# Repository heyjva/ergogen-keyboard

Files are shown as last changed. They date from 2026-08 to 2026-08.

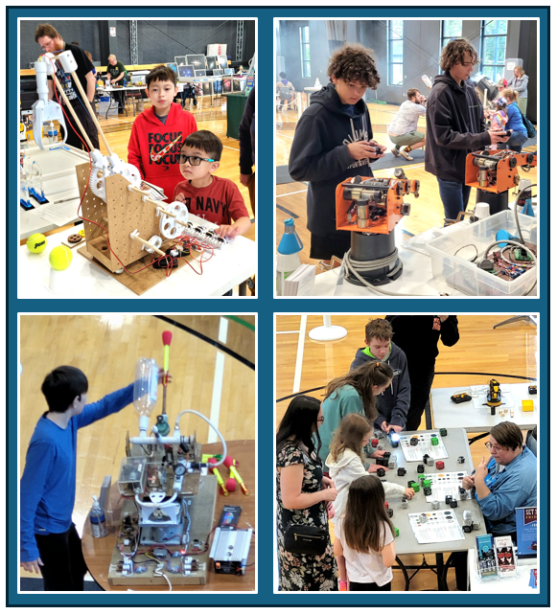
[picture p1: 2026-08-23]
footprints/4_Photos_Kitsap_Stem_Expo_2025.png

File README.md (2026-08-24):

# ergogen-keyboard

Ergogen keyboard project, migrated to **KiCad 8** with a local preview/edit app.

This repo contains the full keyboard definition: a **split ergo board** with a
matrix, thumb cluster, rotary encoder and its own nice!nano controller **per
half**. It is a **wireless split** (independent MCU on each half, e.g. ZMK).
The numpad that used to live in the old `heyjva/ergogen` fork is **not** part of
this repo.

## Split layout: left + right

One `config.yaml` generates **both halves** as separate PCBs via ergogen's
`mirror`:

- The `points.zones.main` / `thumb` zones carry a `mirror:` block, so ergogen
  emits `mirror_*` points for the right half.
- `pcbs.main_left` selects source points (`where: -/mirror_/`); `pcbs.main_right`
  selects mirror points (`where: /mirror_/`) and anchors positioned footprints
  to `mirror_main_*` refs.
- The right half's **side-actuated power/reset switches** get `+180°` rotation
  so their actuators face the mirrored board edge.
- Both halves share the same net names (P11..P21, P2, etc.). That is safe
  because they are **separate PCBs / separate MCUs** — the nets never physically
  connect across boards.

Ergogen writes `output/pcbs/main_left.kicad_pcb` and
`output/pcbs/main_right.kicad_pcb`. The KiCad projects live in:

| Path | Description |
|---|---|
| `kicad/left/`  | Left half KiCad project. **Fully routed** + DRC-clean (JLCPCB rules). |
| `kicad/right/` | Right half KiCad project (mirror image). Generated, **not yet routed**. |
| `kicad/3d_models/` | Shared STEP/WRL 3D models (symlinked into each half). |

Build/regenerate a half's KiCad project from ergogen output:

```bash
node <ergogen> . -o output           # regenerate both PCBs
./kicad/build_kicad_project.sh right  # (re)build the right-half project
# ./kicad/build_kicad_project.sh left   # WARNING: wipes the routed left PCB
```

## Contents

| Path | Description |
|---|---|
| `config.yaml` | Ergogen definition (KiCad 8, Back-side hotswap, mirrored split). |
| `key.json` | Original KLE source, kept for reference. |
| `footprints/ceoloide/` | Vendored KiCad 8 footprints used by the board. |
| `output/` | Generated output (DXF outlines + `main_left`/`main_right` PCBs). |

## Footprints (KiCad 8)

The board uses these footprints from
[`ceoloide/ergogen-footprints`](https://github.com/ceoloide/ergogen-footprints),
vendored under `footprints/ceoloide/`:

- `switch_choc_v1_v2` — Kailh Choc hotswap switches
- `diode_tht_sod123` — per-key diodes
- `mcu_nice_nano` — nice!nano controller
- `encoder_evqwgd001` — Panasonic EVQWGD001 rotary encoder
- `battery_connector_jst_ph_2`, `power_switch_smd_side`,
  `reset_switch_smd_side`, `mounting_hole_plated`

Keys/diodes/MCU/encoder are on the **Back (`B`)** side; the side-actuated
power/reset switches are on the **Front (`F`)**. Each half is non-reversible on
its own; the *split* mirror is what produces the right half.

## Wiring notes (important for firmware)

The matrix uses 7 columns and 4 rows:

- Columns: `P21 P20 P19 P18 P17 P16 P15`
- Rows: `P14 P13 P12 P11`

The nice!nano does **not** break out physical pins named `P11`, `P12`, `P13`,
or `P17`. In `config.yaml` those logical nets are therefore routed onto spare
physical nice!nano pins, and the nice!view SPI signals are assigned as follows:

| Logical net | Physical nice!nano pin |
|---|---|
| `P17` (index column) | `P4` |
| `P13` (home row) | `P5` |
| `P12` (top row) | `P6` |
| `P11` (num row) | `P7` |
| `MOSI` (display) | `P8` |
| `SCK` (display) | `P9` |
| `CS` (display) | `P3` |

The remaining matrix nets (`P21 P20 P19 P18 P16 P15 P14`) map 1:1 to the
same-named physical pins. **Update your firmware pin map to match the physical
pins above.** (In the original fork these four nets were never connected to the
MCU — this project fixes that.)

## 3D models

The footprints are wired to reference 3D models but the model asset files are
not included here. To see 3D renders in KiCad, drop the appropriate `.step` /
`.wrl` files into `models/` and point the footprints' `*_3dmodel_filename`
params at them. 3D models do **not** render in the browser preview — only in
KiCad.

## Previewing & editing locally

The preview/edit app is a patched fork of
[`ceoloide/ergogen-gui`](https://github.com/ceoloide/ergogen-gui) at
[`heyjva/ergogen-gui`](https://github.com/heyjva/ergogen-gui). It runs a local
web server and, unlike the stock GUI, includes a **"Save to File"** button that
writes changes straight back to this repo's `config.yaml` — and it works in
**Firefox / Zen**.

### One-time setup

```bash
# clone both repos as siblings
git clone https://github.com/heyjva/ergogen-keyboard.git
git clone https://github.com/heyjva/ergogen-gui.git

cd ergogen-gui
npm install -g pnpm   # if you don't have pnpm
PNPM_CONFIG_BLOCK_EXOTIC_SUBDEPS=false \
  ERGOGEN_VERSION=github:ceoloide/ergogen#v4.3.0 \
  pnpm install --no-frozen-lockfile
```

### Run it

```bash
cd ergogen-gui
./start.sh
```

This launches:

1. a tiny **save-helper** on `http://localhost:3001` (writes `config.yaml`), and
2. the **GUI** on `http://localhost:3000`.

Open <http://localhost:3000> in **Firefox / Zen**. The editor auto-loads this
repo's `config.yaml`. Edit it, then click **Save to File** (or press
**Ctrl/Cmd+S**) to write your changes back to `config.yaml` on disk. Commit with
git as usual.

> The save-helper is required because Firefox cannot write local files directly
> from a web page. It binds to `127.0.0.1` only and only ever writes this repo's
> `config.yaml`.

If you keep the repos somewhere other than as siblings, point the helper at the
file explicitly:

```bash
CONFIG_PATH=/absolute/path/to/ergogen-keyboard/config.yaml ./start.sh
```

## Regenerating outputs from the command line

The GUI is for previewing/editing. To regenerate the DXF/KiCad files on disk
from `config.yaml`, run Ergogen v4.3.0 against this folder:

```bash
# from a checkout of ceoloide/ergogen at branch v4.3.0
node /path/to/ergogen/src/cli.js . -o output
```

This reads `config.yaml` + `footprints/` and writes `output/`.

## Complete KiCad project (schematic + PCB)

Ergogen only produces a `.kicad_pcb` (footprints + net connectivity, no
schematic). The `kicad/` folder contains a **complete, openable KiCad project**
generated from that PCB:

| File | Description |
|---|---|
| `kicad/keyboard.kicad_pro` | KiCad project file (open this) |
| `kicad/keyboard.kicad_pcb` | The PCB (copy of `output/pcbs/main.kicad_pcb`) |
| `kicad/keyboard.kicad_sch` | Generated schematic |
| `kicad/keyboard-schematic.pdf` | Rendered schematic (preview) |
| `kicad/gen_schematic.py` | Schematic generator (uses KiCad's `pcbnew`) |
| `kicad/build_kicad_project.sh` | Regenerates the whole project |

Open **`kicad/keyboard.kicad_pro`** in KiCad.

### About the schematic

The schematic is generated from the PCB's netlist (KiCad has no built-in
PCB→schematic reverse). Each component is a real symbol laid out on a grid, and
connectivity is expressed with **global net labels** on each pin (the standard
approach for auto-generated keyboard schematics). It's electrically correct and
ERC-readable, but laid out on a grid rather than hand-drawn — useful for
verification, BOM, and reference, not a pretty hand-routed diagram.

### Regenerating the KiCad project

Requires KiCad installed (`pcbnew` python module + `kicad-cli`):

```bash
# after regenerating output/ with ergogen:
./kicad/build_kicad_project.sh
```

### Notes / expected DRC warnings

- **Unconnected items**: the PCB has nets but no routed traces (ergogen doesn't
  route) — route in KiCad. Not an error.
- **`invalid_outline` from ENC1**: the EVQWGD001 encoder footprint adds an
  Edge.Cuts roller cutout that reads as a secondary open contour. Harmless for
  the design; clean it up in KiCad's Edge.Cuts if desired.
- **lib_footprint / lib_symbol warnings**: footprints are embedded in the PCB
  and standard KiCad symbol libs are used; these "library not in config"
  warnings are cosmetic.

### JLCPCB design rules

The project is pre-configured for JLCPCB's standard **2-layer, 1oz FR-4**
process (their cheapest tier), so DRC catches anything they can't make:

- Numeric constraints live in `kicad/keyboard.kicad_pro`
  (`board.design_settings.rules`): min track/clearance 0.1 mm, min via
  0.45 mm / 0.3 mm drill, min PTH drill 0.3 mm, min hole-to-hole 0.5 mm,
  min copper-to-edge 0.2 mm, min silk text 1.0 mm. These are JLCPCB's true
  standard-process minimums for 1oz 2-layer.
- The auto-router routes down to these limits (0.1 mm track/space, 0.1 mm
  hole-to-copper). That is manufacturable at JLCPCB but leaves little margin;
  the default net class uses a more comfortable 0.25 mm track / 0.1 mm space.
- JLC-specific checks (annular ring, edge clearance, hole-to-hole, silk
  width/height, silk-to-pad, SMD pad clearance) are in
  `kicad/keyboard.kicad_dru`. Note the via annular-ring rule is 0.05 mm:
  0.45 mm-via/0.3 mm-hole is a standard no-extra-cost JLC via; the 0.13 mm
  annular guideline applies to component PTH pads, not tented vias.
- These files are **not** overwritten by `build_kicad_project.sh` (which only
  regenerates the `.kicad_pcb`/`.kicad_sch`), so the rules persist across
  rebuilds. The router's "Fix DRC settings after routing" option WILL rewrite
  the `.kicad_pro` constraints, so re-check them after routing.
- Source: <https://jlcpcb.com/capabilities/pcb-capabilities>

Run a rules check any time with:

```bash
kicad-cli pcb drc kicad/keyboard.kicad_pcb --severity-error
```

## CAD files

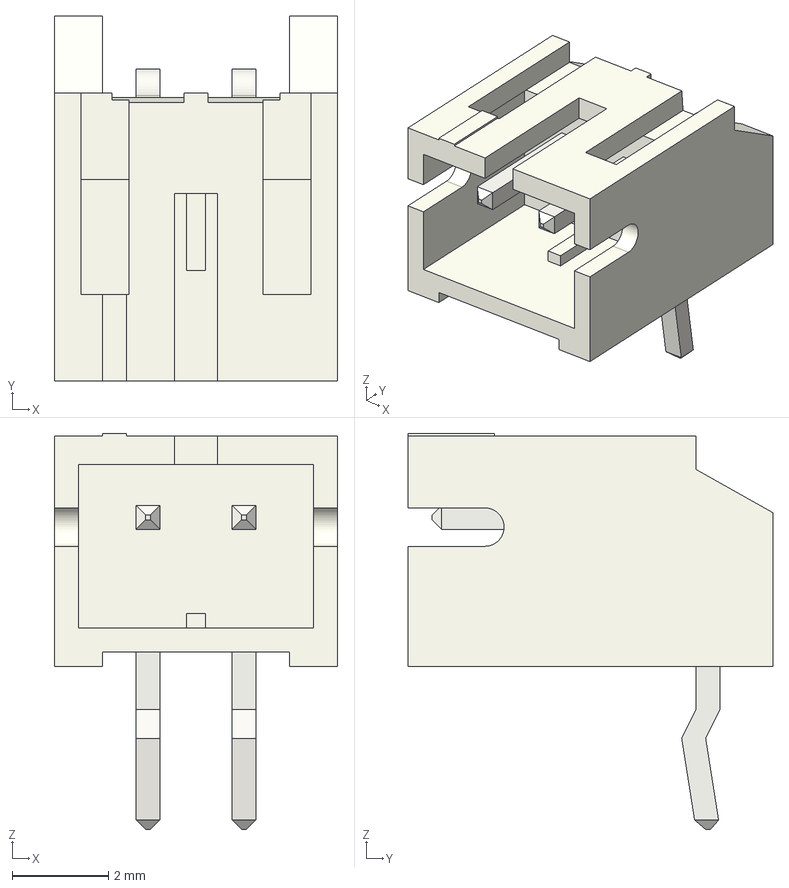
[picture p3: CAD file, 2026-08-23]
kicad/3d_models/JST_PH_S2B_2pin.step
5.90 x 7.60 x 8.25 mm

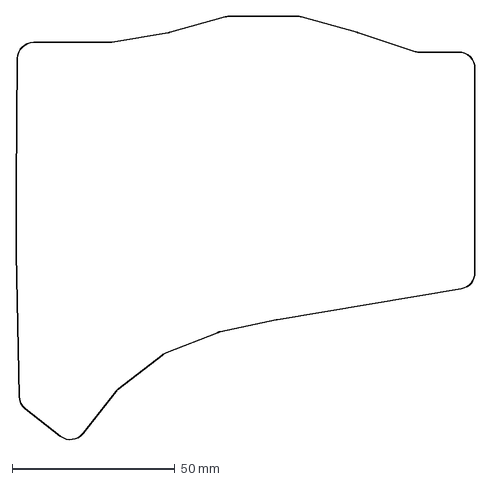
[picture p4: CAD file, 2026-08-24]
output/outlines/board_right.dxf
141.0 x 130.8 mm

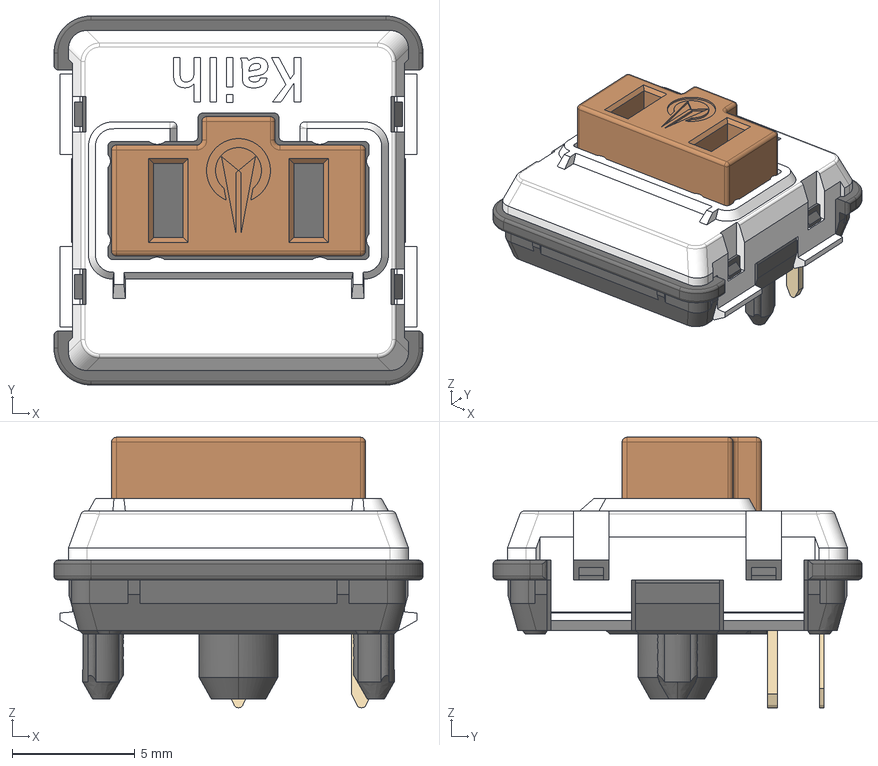
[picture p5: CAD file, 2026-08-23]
kicad/3d_models/Choc_V1_Switch.step
15.0 x 15.0 x 11.0 mm

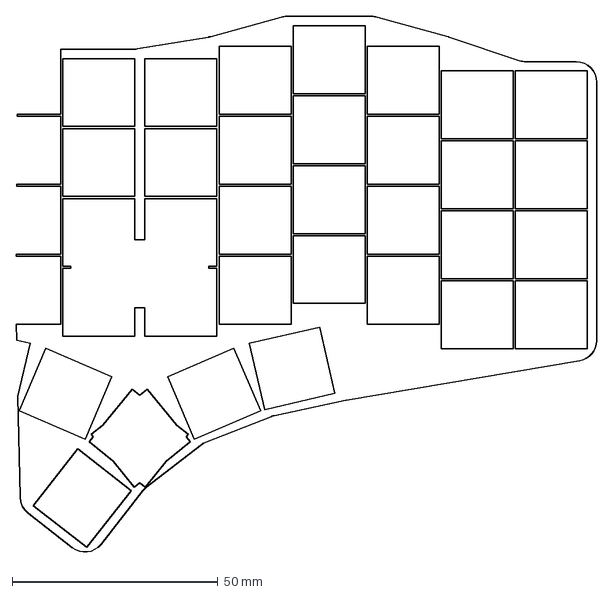
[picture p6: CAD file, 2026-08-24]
output/outlines/combo_right.dxf
141.0 x 130.8 mm

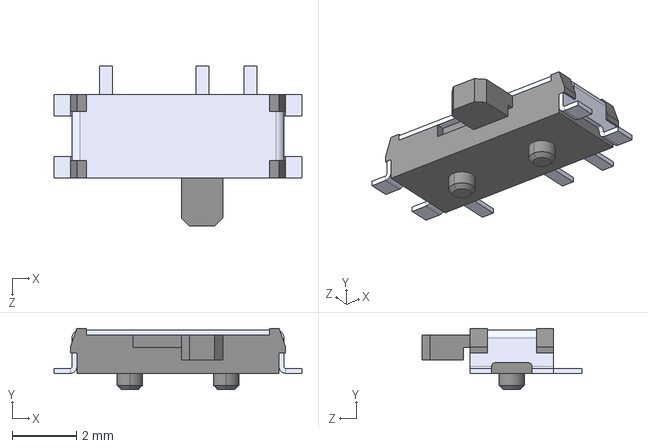
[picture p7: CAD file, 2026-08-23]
kicad/3d_models/Switch_Power.step
7.72 x 1.91 x 4.98 mm

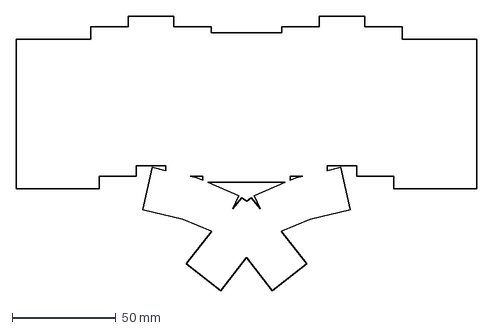
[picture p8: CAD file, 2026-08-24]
output/outlines/raw.dxf
222.0 x 132.1 mm

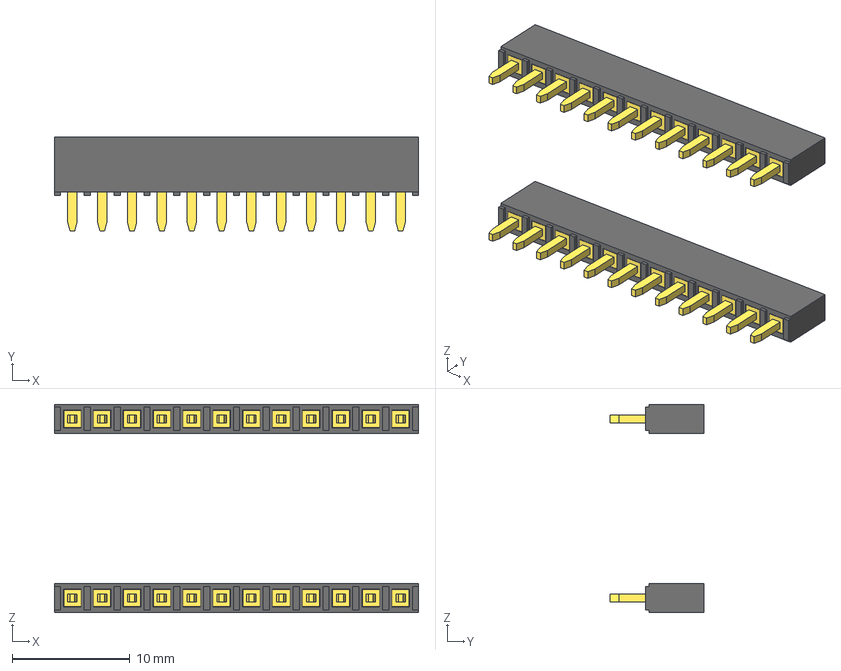
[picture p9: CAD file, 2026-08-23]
kicad/3d_models/PinSocket_2.54mm_5mm_2x-12.step
31.0 x 8.00 x 17.7 mm

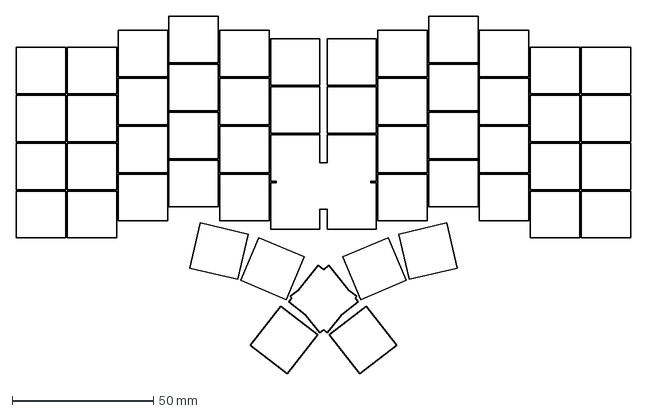
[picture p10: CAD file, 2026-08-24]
output/outlines/keys.dxf
217.5 x 126.7 mm

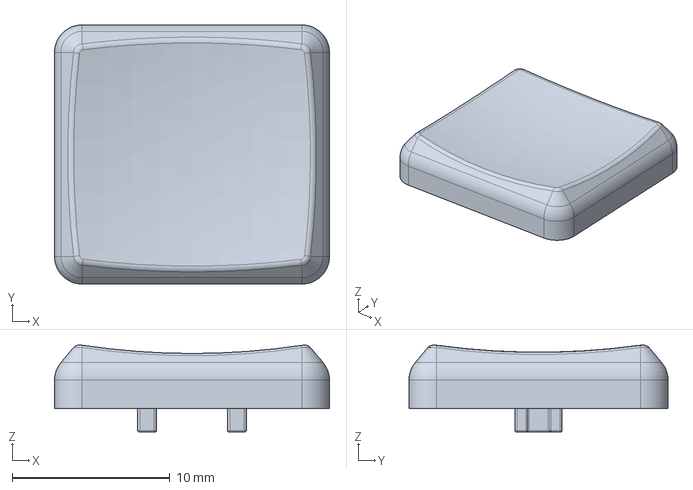
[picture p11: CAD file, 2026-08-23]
kicad/3d_models/Choc_V1_Keycap_MBK_Black_1u.step
17.4 x 16.4 x 5.52 mm

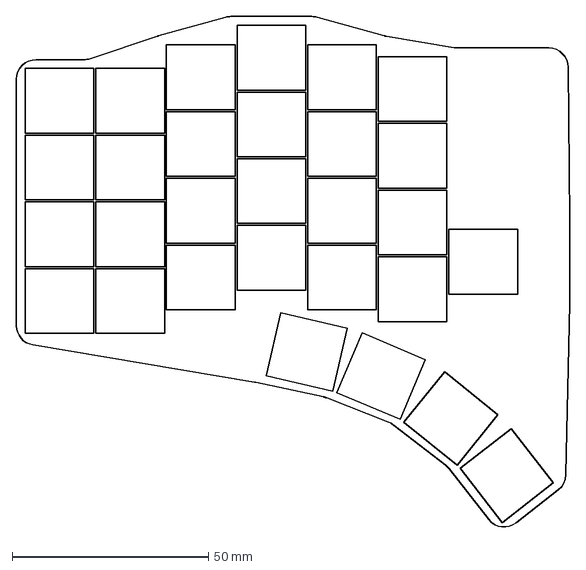
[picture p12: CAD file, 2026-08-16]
output/outlines/combo.dxf
141.0 x 130.8 mm

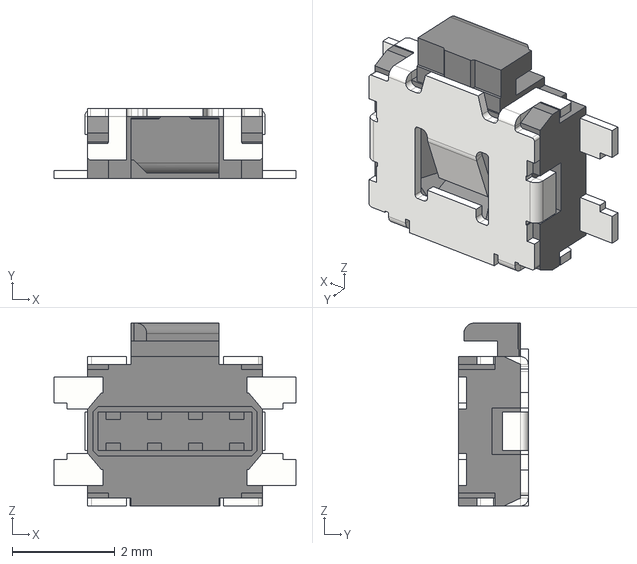
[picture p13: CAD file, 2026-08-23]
kicad/3d_models/Switch_Reset.step
4.70 x 1.35 x 3.55 mm

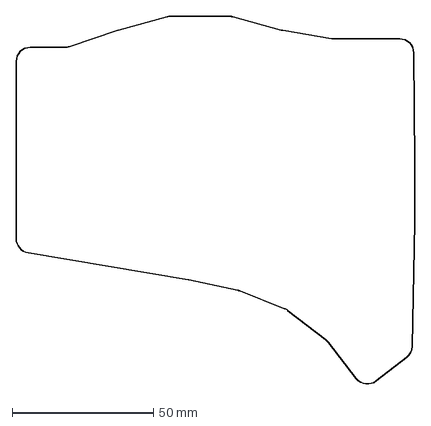
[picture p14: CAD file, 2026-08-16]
output/outlines/board.dxf
141.0 x 130.8 mm

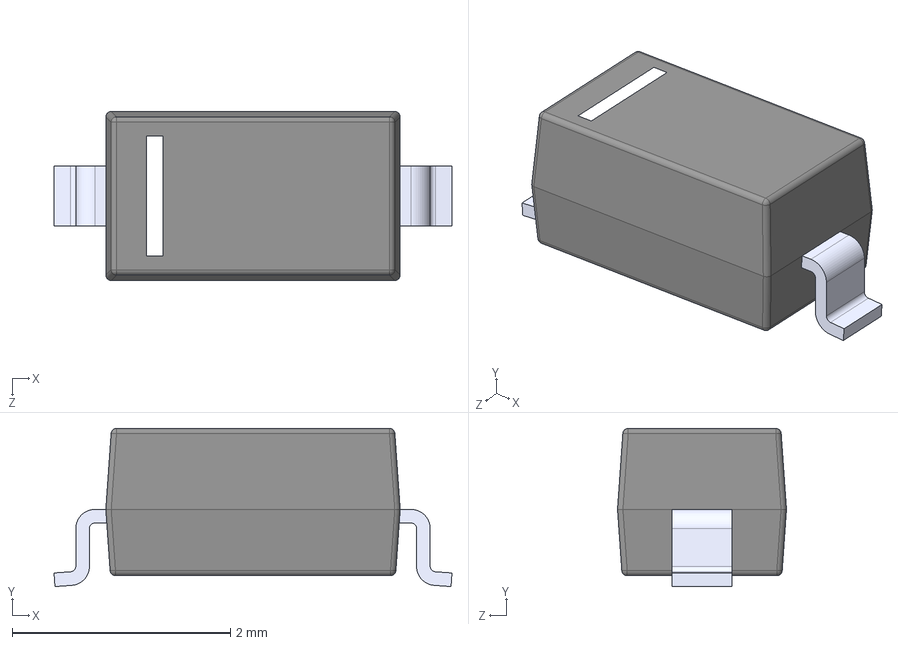
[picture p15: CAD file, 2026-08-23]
kicad/3d_models/Diode_1N4148W.step
3.65 x 1.45 x 1.55 mm

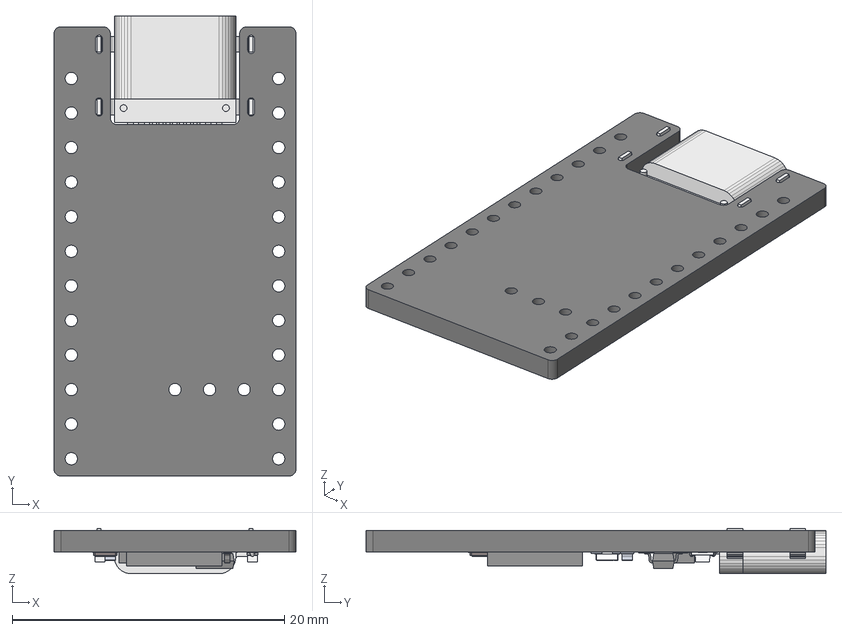
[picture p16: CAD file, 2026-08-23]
kicad/3d_models/Nice_Nano_V2.step
17.8 x 33.8 x 3.34 mm
User Library-TYPE-C-31-M-14.step
MICRO_603 resistor 102
micro_crystal 5x3
MICRO_led
micro_MIC5219

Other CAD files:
kicad/3d_models/Choc_V1_Hotswap.step

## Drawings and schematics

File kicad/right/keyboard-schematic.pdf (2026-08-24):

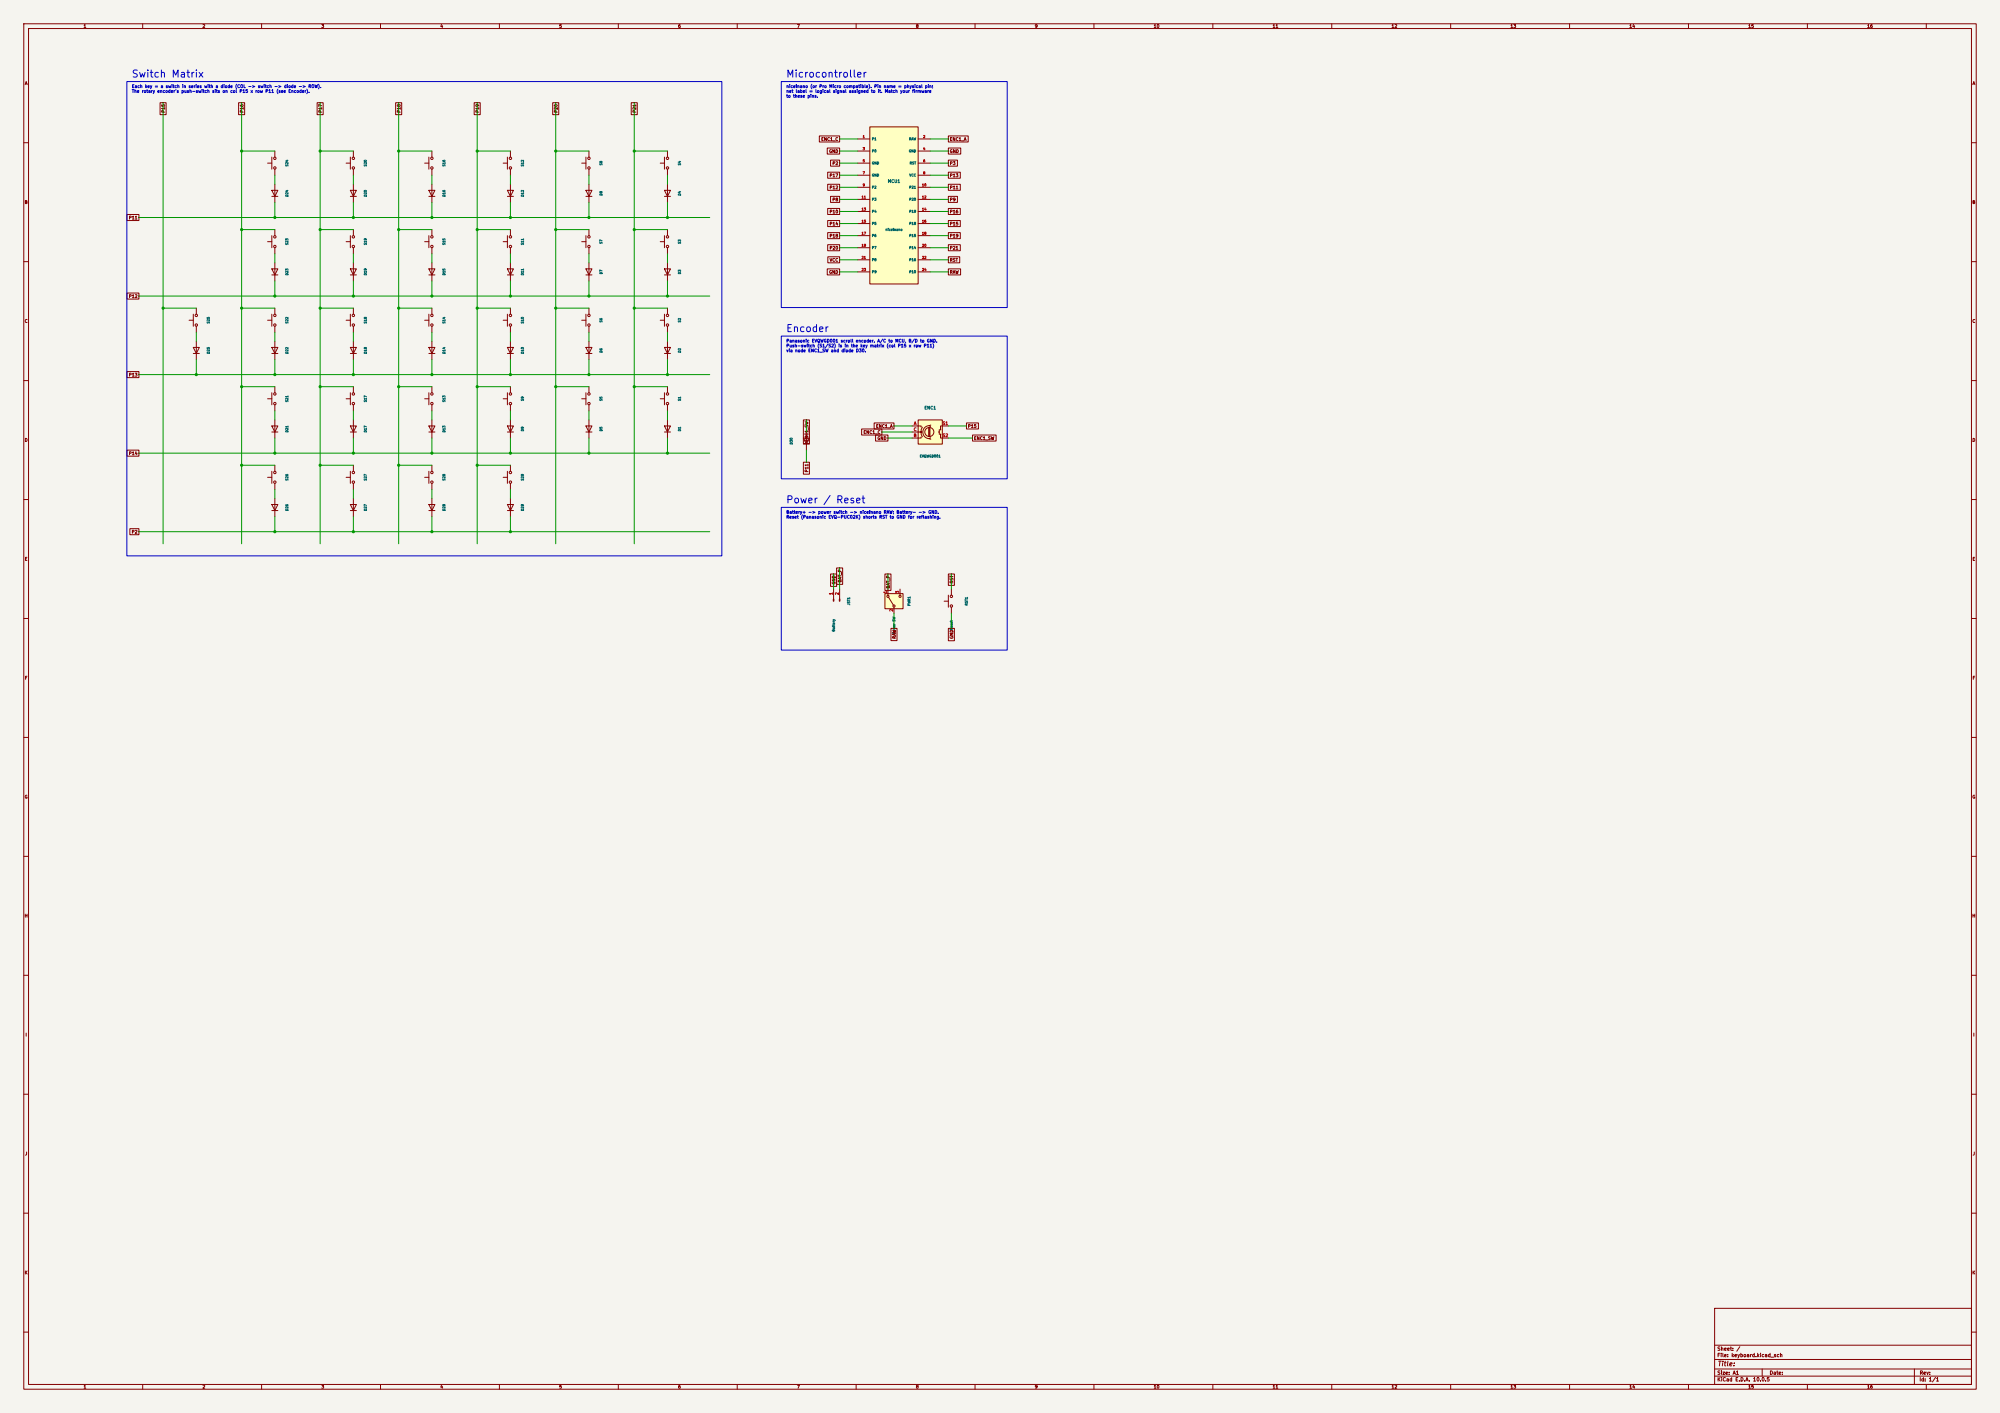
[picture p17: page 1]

Each key = a switch in series with a diode (COL -> switch -> diode -> ROW). The rotary encoder's push-switch sits on col P15 x row P11 (see Encoder).

nice!nano (or Pro Micro compatible). Pin name = physical pin; net label = logical signal assigned to it. Match your firmware
P3 BAT_P
24 MCU1

Panasonic EVQWGD001 scroll encoder. A/C to MCU, B/D to GND. Push-switch (S1/S2) is in the key matrix (col P15 x row P11) via node ENC1_SW and diode D30.

Battery+ -> power switch -> nice!nano RAW; Battery- -> GND. Reset (Panasonic EVQ-PUC02K) shorts RST to GND for reflashing.

Size: A1 | Rev:
KiCad E.D.A. 10.0.5 | Id: 1/1

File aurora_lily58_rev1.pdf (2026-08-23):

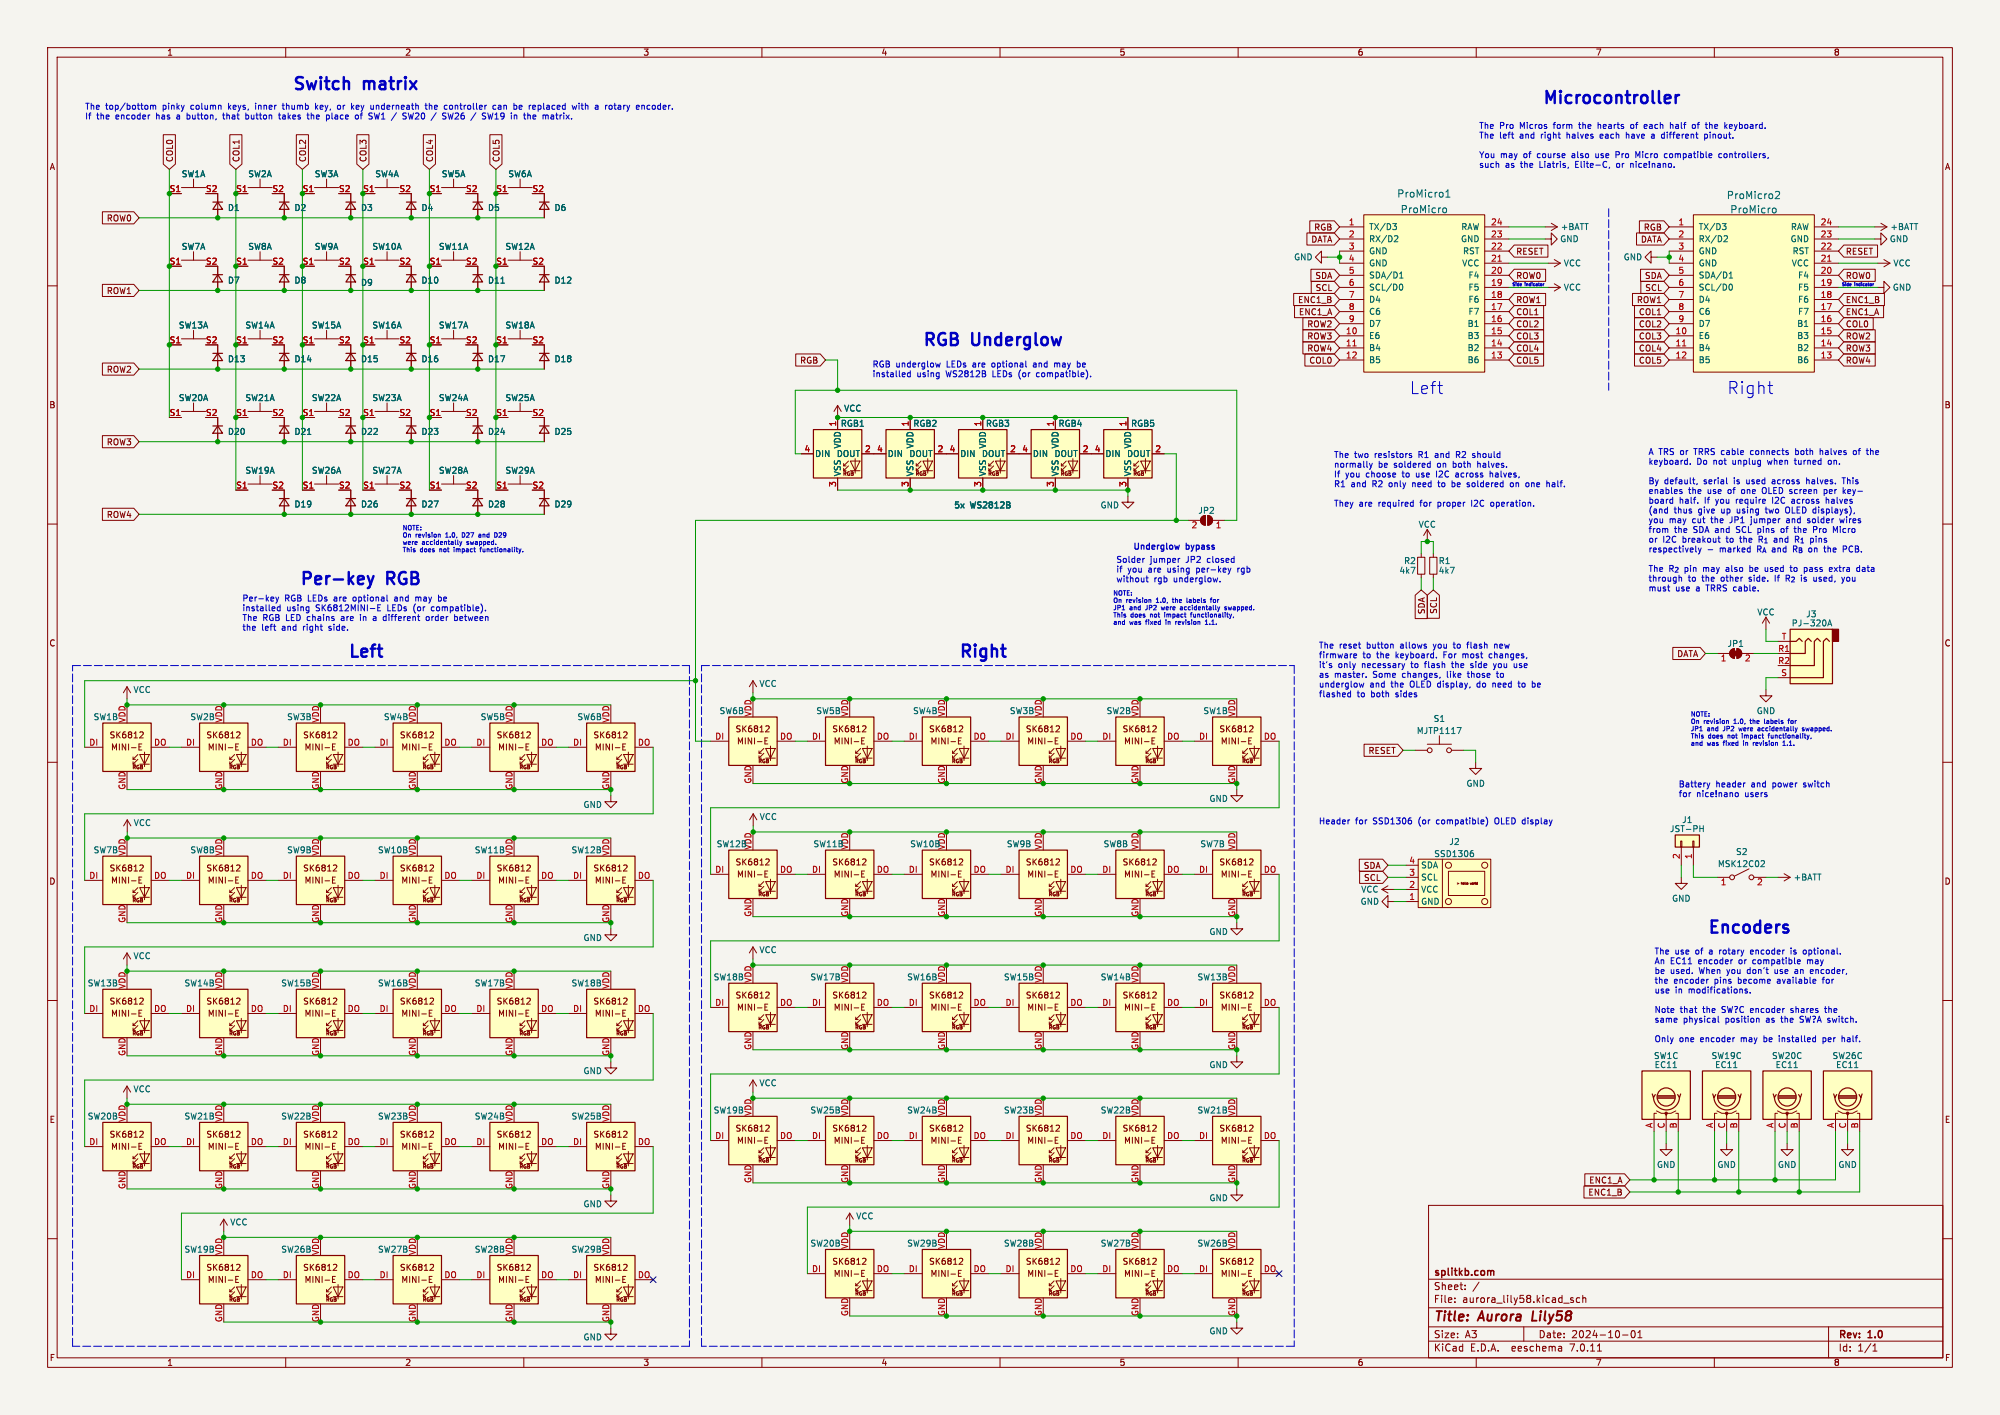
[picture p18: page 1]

Side indicator The reset button allows you to flash new

(and thus give up using two OLED displays), you may cut the JP1 jumper and solder wires

from the SDA and SCL pins of the Pro Micro

as master. Some changes, like those to
flashed to both sides
RESET SDA

Battery header and power switch

File: aurora_lily58.kicad_sch Sheet: / splitkb.com

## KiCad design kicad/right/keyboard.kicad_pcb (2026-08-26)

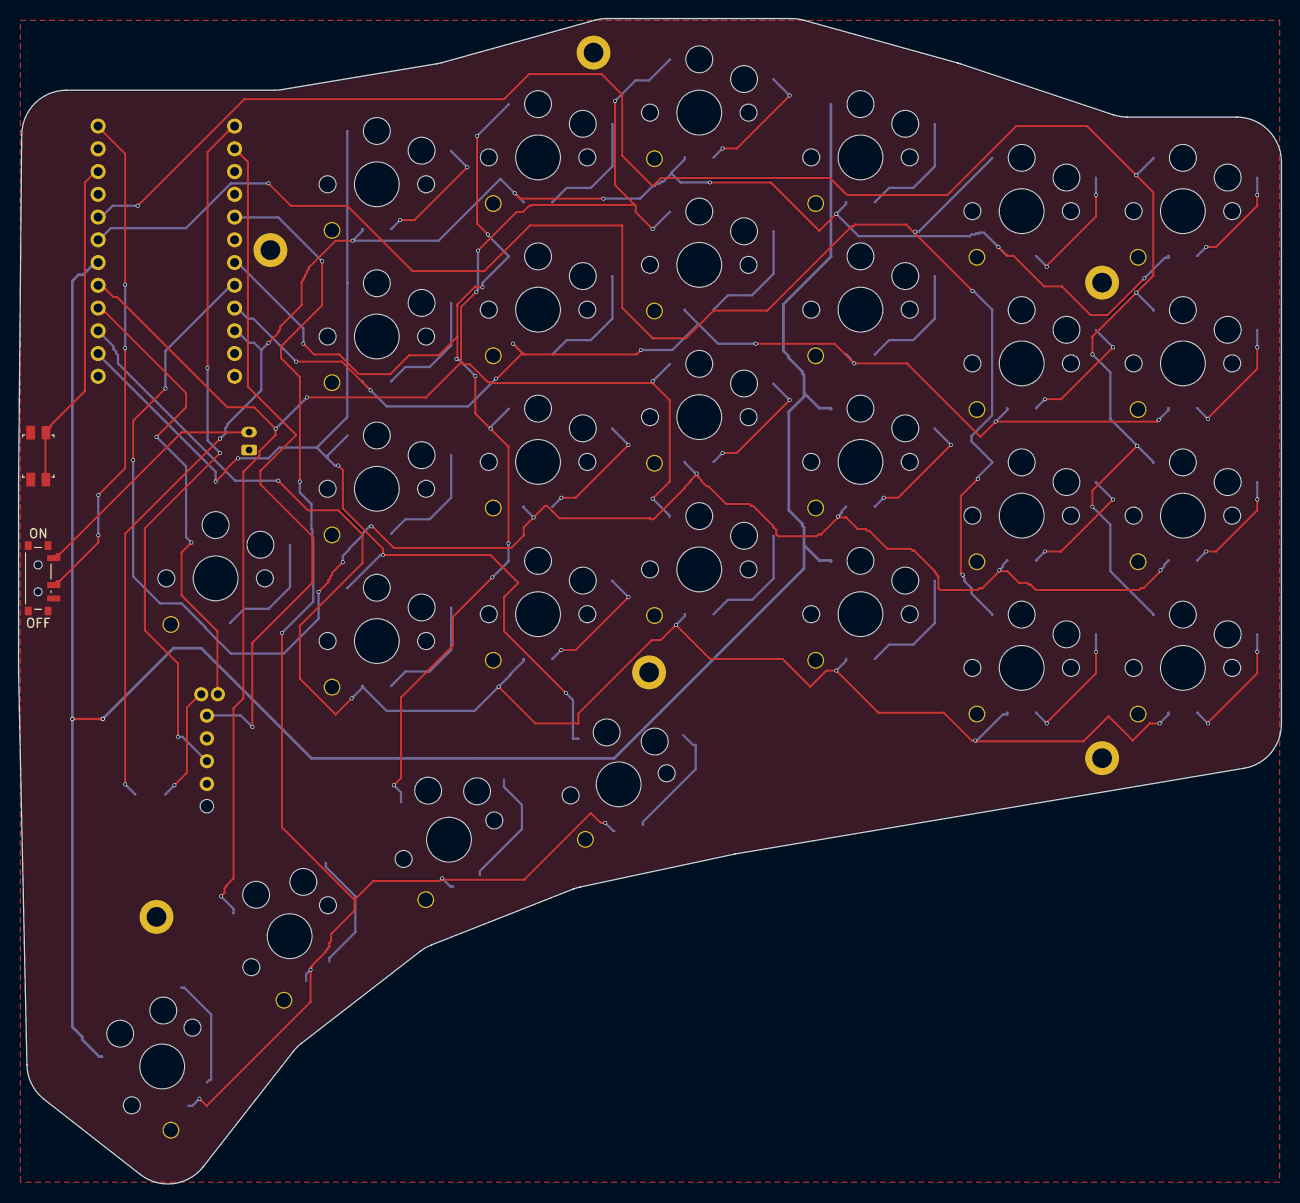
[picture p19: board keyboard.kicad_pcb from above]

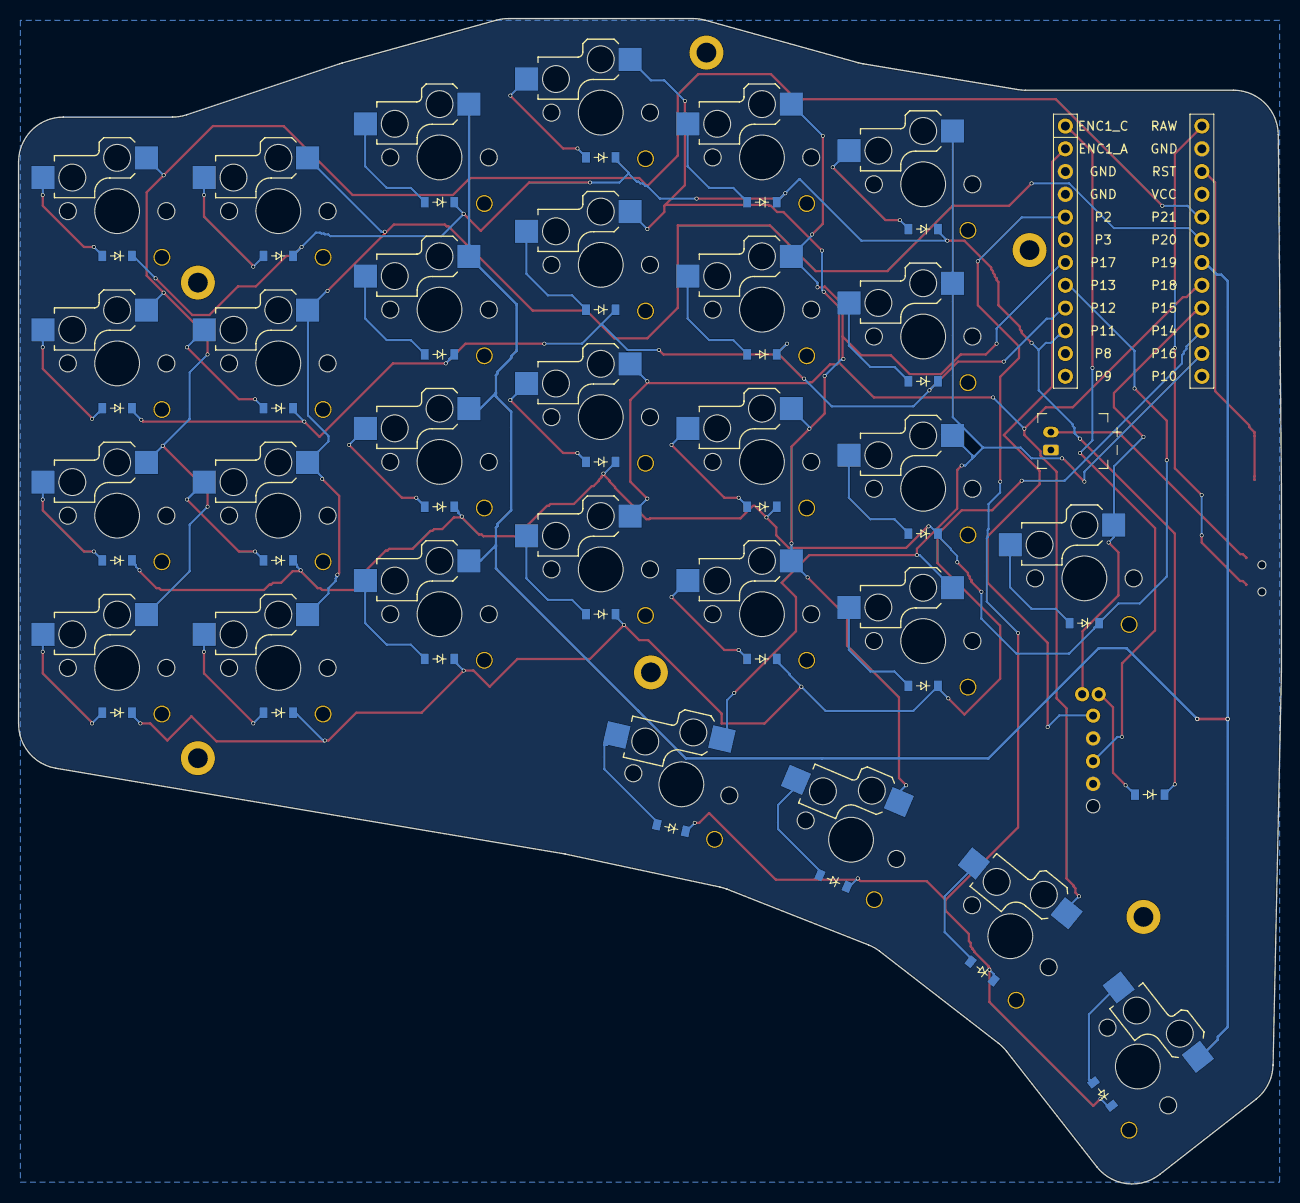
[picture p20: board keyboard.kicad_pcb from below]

Board: 2 copper layers, 141.0 x 130.1 mm, 70 parts (68 on the bottom side), 48 nets.

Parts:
D1, D2, D3, D4, D5, D6, D7, D8, D9, D10, D11, D12, D13, D14, D15, D16, D17, D18, D19, D20, D21, D22, D23, D24, D25, D26, D27, D28, D29, D30: diode_tht_sod123
ENC1: encoder_evqwgd001
H1, H2, H3, H4, H5, H6: mounting_hole_plated
JST1: battery_connector_jst_ph_2
MCU1: mcu_nice_nano
PWR1: power_switch_smd_side
RST1: reset_switch_smd_side
S1, S2, S3, S4, S5, S6, S7, S8, S9, S10, S11, S12, S13, S14, S15, S16, S17, S18, S19, S20, S21, S22, S23, S24, S25, S26, S27, S28, S29: switch_choc_v1_v2

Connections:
BAT_P: JST1.2, PWR1.1
ENC1_A: ENC1.A, MCU1.2
ENC1_C: ENC1.C, MCU1.1
ENC1_SW: D30.2, ENC1.2
GND: ENC1.B, ENC1.D, JST1.1, MCU1.3, MCU1.4, MCU1.23, RST1.1, RST1.3
P2: D26.1, D27.1, D28.1, D29.1, MCU1.5
P11: D4.1, D8.1, D12.1, D16.1, D20.1, D24.1, D30.1, MCU1.10
P12: D3.1, D7.1, D11.1, D15.1, D19.1, D23.1, MCU1.9
P13: D2.1, D6.1, D10.1, D14.1, D18.1, D22.1, D25.1, MCU1.8
P14: D1.1, D5.1, D9.1, D13.1, D17.1, D21.1, MCU1.15
P15: ENC1.1, MCU1.16, S25.1
P16: MCU1.14, S21.1, S22.1, S23.1, S24.1, S26.1
P17: MCU1.7, S17.1, S18.1, S19.1, S20.1, S27.1
P18: MCU1.17, S13.1, S14.1, S15.1, S16.1, S28.1
P19: MCU1.18, S9.1, S10.1, S11.1, S12.1, S29.1
P20: MCU1.19, S5.1, S6.1, S7.1, S8.1
P21: MCU1.20, S1.1, S2.1, S3.1, S4.1
RAW: MCU1.24, PWR1.2
RST: MCU1.22, RST1.2, RST1.4
mirror_home_cluster: D27.2, S27.2
mirror_index_bottom: D17.2, S17.2
mirror_index_home: D18.2, S18.2
mirror_index_num: D20.2, S20.2
mirror_index_top: D19.2, S19.2
mirror_inner_bottom: D21.2, S21.2
mirror_inner_cluster: D26.2, S26.2
mirror_inner_home: D22.2, S22.2
mirror_inner_num: D24.2, S24.2
mirror_inner_top: D23.2, S23.2
mirror_middle_bottom: D13.2, S13.2
mirror_middle_home: D14.2, S14.2
mirror_middle_num: D16.2, S16.2
mirror_middle_top: D15.2, S15.2
mirror_oouter_cluster: D29.2, S29.2
mirror_outer_bottom: D1.2, S1.2
mirror_outer_cluster: D28.2, S28.2
mirror_outer_home: D2.2, S2.2
mirror_outer_num: D4.2, S4.2
mirror_outer_top: D3.2, S3.2
mirror_pinky_bottom: D5.2, S5.2
mirror_pinky_home: D6.2, S6.2
mirror_pinky_num: D8.2, S8.2
mirror_pinky_top: D7.2, S7.2
mirror_ring_bottom: D9.2, S9.2
mirror_ring_home: D10.2, S10.2
mirror_ring_num: D12.2, S12.2
mirror_ring_top: D11.2, S11.2
mirror_single_home: D25.2, S25.2

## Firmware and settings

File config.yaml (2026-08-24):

meta:
  engine: 4.1.0 # Minimum Ergogen version required for KiCad 8 footprints
units:
  # Proxy Spacing Variables
  kx: cx
  ky: cy
  # Padding Variables
  px: kx + 4
  py: ky + 4
points:
  zones:
    main:
      # Global placement: shift the whole board so it sits at the top-left of
      # the A3 sheet working area (~15mm inset). Everything (thumb, outlines,
      # footprints) cascades from this zone, so this translates the board as a
      # rigid unit without affecting geometry or wiring.
      anchor:
        shift: [26, -87.5]
      # Mirror the whole main zone to create the RIGHT half. Ergogen generates
      # `mirror_*` points for every key; the two halves are emitted as separate
      # PCBs (main_left / main_right) in the pcbs: section below, so the shared
      # column/row net names (P11..P21, P2) never collide across boards.
      mirror:
        ref: main_outer_num
        distance: 200
      key:
        padding: 1ky
        spread: 1kx
      columns:
        outer:
          key.column_net: P21
        pinky:
          key.stagger:
          key.column_net: P20
        ring:
          key.stagger: 6
          key.column_net: P19
        middle:
          key.stagger: 5
          key.column_net: P18
        index:
          key.stagger: -5
          key.column_net: P17
        inner:
          key.stagger: -3
          key.column_net: P16
        single:
          key:
            stagger: -10
          rows.num.skip: true
          rows.top.skip: true
          rows.bottom.skip: true
          key.column_net: P15
      rows:
        bottom:
          row_net: P14
        home:
          row_net: P13
        top:
          row_net: P12
        num:
          row_net: P11
    thumb:
      key:
        padding: 1ky
        spread: 1kx
      anchor:
        ref: main_inner_bottom
        shift: [-27,-16]
      # Mirror the thumb cluster onto the right half across the same axis as
      # the main zone, so mirror_thumb_* points are generated for main_right.
      mirror:
        ref: main_outer_num
        distance: 200
      columns:
        inner:
          key.column_net: P16
        home:
          key:
            rotate: 3
            shift: [2.2,-1.3]
            column_net: P17
        outer:
          key:
            shift: [5.5,-2.]
            column_net: P18
        oouter:
          key:
            shift: [8.5,-2.5]
            column_net: P19
      rows:
        cluster:
          splay: -13
          row_net: P2
outlines:
  raw:
    - what: rectangle
      where: true
      bound: true
      size: [px, py]
  keys:
    - what: rectangle
      where: true
      bound: false
      size: [kx-0.5,ky-0.5]
  board:
    - what: polygon
      operation: stack
      points:
        - ref: main_outer_num
          shift: [-0.5px,0.5py]
        - ref: main_pinky_num
          shift: [-0.5px,0.5py]
        - ref: main_ring_num
          shift: [-0.5px,0.5py]
        - ref: main_middle_num
          shift: [-0.5px,0.5py]
        - ref: main_middle_num
          shift: [0.5px,0.5py]
        - ref: main_index_num
          shift: [0.5px,0.5py]
        - ref: main_inner_num
          shift: [0.5px,0.5py]
        - ref: main_inner_num
          shift: [1.8px,0.5py]
        - ref: main_single_home
          shift: [1px,0.5py]
        - ref: main_single_home
          shift: [1px,-0.5py]
        - ref: thumb_oouter_cluster
          shift: [0.5px,0.5py]
        - ref: thumb_oouter_cluster
          shift: [0.5px,-0.5py]
        - ref: thumb_oouter_cluster
          shift: [-0.5px,-0.5py]
        - ref: thumb_outer_cluster
          shift: [-0.5px,-0.5py]
        - ref: thumb_home_cluster
          shift: [-0.5px,-0.5py]
        - ref: thumb_inner_cluster
          shift: [-0.5px,-0.5py]
        - ref: main_outer_bottom
          shift: [-0.5px,-0.5py]
      fillet: 5
  combo:
    - name: board
    - operation: subtract
      name: keys
  # ---- RIGHT-half outline: same board polygon but built from the mirror_*
  # points so it forms the mirror image for main_right. ----
  board_right:
    - what: polygon
      operation: stack
      points:
        - ref: mirror_main_outer_num
          shift: [-0.5px,0.5py]
        - ref: mirror_main_pinky_num
          shift: [-0.5px,0.5py]
        - ref: mirror_main_ring_num
          shift: [-0.5px,0.5py]
        - ref: mirror_main_middle_num
          shift: [-0.5px,0.5py]
        - ref: mirror_main_middle_num
          shift: [0.5px,0.5py]
        - ref: mirror_main_index_num
          shift: [0.5px,0.5py]
        - ref: mirror_main_inner_num
          shift: [0.5px,0.5py]
        - ref: mirror_main_inner_num
          shift: [1.8px,0.5py]
        - ref: mirror_main_single_home
          shift: [1px,0.5py]
        - ref: mirror_main_single_home
          shift: [1px,-0.5py]
        - ref: mirror_thumb_oouter_cluster
          shift: [0.5px,0.5py]
        - ref: mirror_thumb_oouter_cluster
          shift: [0.5px,-0.5py]
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

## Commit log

2026-08-16 Initial KiCad 8 keyboard project
    - Migrate keyboard from legacy KiCad 6 fork to KiCad 8 (template: kicad8)
    - Use ceoloide KiCad 8 footprints: switch_choc_v1_v2, diode_tht_sod123,
    display_nice_view, mcu_nice_nano (vendored under footprints/ceoloide/)
    - Single-side (Back), hotswap switches, non-reversible
    - Fix wiring: connect matrix nets P11/P12/P13/P17 + SPI (MOSI/SCK/CS) to
    real nice!nano pins (were orphaned in the original design)
    - Remove numpad; keyboard-only self-contained repo
    - Validated against ergogen v4.3.0; includes generated output/
    [board.dxf, combo.dxf, keys.dxf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]
2026-08-16 Position board at top-left of A3 sheet working area
    Add an anchor shift ([26, -87.5]) to the root 'main' zone so the whole board
    (points, outlines, footprints all cascade from it) is translated as a rigid
    unit to sit at the top-left of the A3 drawing sheet (~15mm inset), so it opens
    properly placed in KiCad. Board bbox is now X:15..156 Y:15..145, comfortably
    within the A3 frame. Pure translation; geometry and wiring unchanged.
    Regenerated output/.
    [board.dxf, combo.dxf, keys.dxf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]
2026-08-16 Add Panasonic EVQWGD001 rotary encoders (x2)
    - Add KiCad 8 (footprint syntax) port of the EVQWGD001 scroll encoder
    footprint (converted from the legacy ergogen 'scrollwheel' module footprint)
    at footprints/ceoloide/encoder_evqwgd001.js
    - Place two encoders on the Back side with placeholder positions (adjust
    where: to taste)
    - Wire rotary A/C to free nice!nano pins P0/P1 (ENC1) and P2/P10 (ENC2);
    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
    [main.kicad_pcb]
2026-08-16 Wire encoder 1 push-switch into the key matrix
    - Add the EVQWGD001 push-switch (pins 1&2) to the matrix on the free
    intersection column P15 (single) x row P11 (num), via node ENC1_SW, with a
    dedicated diode (ENC1_SW -> P11)
    - Rotary A/C stay on nice!nano P0/P1; B/D on GND
    - Only one encoder (encoder 2 not added)
    - Regenerated output/
    [board.dxf, combo.dxf, keys.dxf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]
2026-08-16 Wiring audit fixes: connect thumb keys, remove nice!view
    - FIX: the 4 thumb cluster keys (inner/home/outer/oouter) had no column_net
    or row_net, leaving them electrically floating (dead keys). Assign columns
    P16-P19 and a new row P2 (nice!nano pin 5), giving each a unique intersection
    - Remove nice!view display (per user) and its now-unused SPI pin assignments
    (MOSI/SCK/CS on P8/P9/P3)
    - Audit result: 30 keys / 30 diodes / 30 unique col x row intersections,
    no MCU pin conflicts, no floating matrix nodes, encoder rotary+switch verified
    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
    [main.kicad_pcb]
2026-08-16 Add reset button, power switch, battery connector, mounting holes
    - Vendor 4 KiCad 8 footprints: reset_switch_tht_top, power_switch_smd_side,
    battery_connector_jst_ph_2, mounting_hole_plated
    - Power path: Battery BAT_P -> power switch -> nice!nano RAW; BAT_N -> GND
    - Reset button: RST -> GND (no GPIO used)
    - 4 M2 plated mounting holes near board corners
    - Placeholder positions (adjust where: to taste)
    - Audit: power path + reset connectivity verified; matrix still 30 keys /
    30 diodes / 30 unique intersections, no conflicts
    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
    [main.kicad_pcb]
2026-08-16 Regenerate with board-sized User paper (was A3)
    The kicad8 template now emits a 'User' paper sized to the board bbox + 15mm
    margin instead of a fixed A3 sheet, so KiCanvas and KiCad open framed on the
    board. This output reflects paper 'User' 171x160.
    [main.kicad_pcb]
2026-08-16 Reposition mounting holes into clear board gaps
    Move the 4 M2 mounting holes to well-spaced spots with good clearance from
    switches and the battery/power/reset components (18-42mm clearance), anchored
    to nearby key points with mm shifts so they track the layout. Fix invalid
    ref (main_outer_cluster -> thumb_outer_cluster).
    [board.dxf, combo.dxf, keys.dxf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]
2026-08-16 Add complete KiCad project (schematic + PCB + project file)
    Ergogen only emits a .kicad_pcb (nets + footprints, no schematic). Add a full
    KiCad project under kicad/:
    - keyboard.kicad_pro: project file (open this in KiCad)
    - keyboard.kicad_pcb: the PCB
    - keyboard.kicad_sch: schematic generated from the PCB netlist via
    gen_schematic.py (pcbnew). Each footprint -> real symbol; connectivity via
    global net labels on each pin. ERC-readable, grid layout.
    - keyboard-schematic.pdf: rendered preview
    - gen_schematic.py + build_kicad_project.sh: regeneration tooling
    All critical nets (matrix P2/P11-P21, encoder, power, reset) verified present
    in the schematic. Also sync output/ + kicad/ with latest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
    [keyboard.kicad_pcb, keyboard.kicad_sch]
2026-08-16 Cleaner schematic: matrix grid + grouped sections
    Rewrite gen_schematic.py to organize the schematic like a real keyboard design:
    - Switch Matrix drawn as a grid (switch + series diode per cell) with COL
    labels on top and ROW labels on the left
    - Separate labelled sections for Microcontroller, Encoder, and Power
    (battery / power switch / reset)
    - Fix encoder pin mapping (RotaryEncoder_Switch uses A/B/C/S1/S2 names) and
    render the encoder push-switch diode (D30, ENC1_SW -> P11)
    All critical nets verified present; ERC violations down from 142 to ~21.
    [keyboard.kicad_sch]
2026-08-16 Match Lily58 schematic styling: boxed sections + matrix grid
    - Wrap each subsystem in a titled section box with a descriptive annotation
    (Switch Matrix, Microcontroller, Encoder, Power/Reset), like the Lily58
    reference schematic
    - Draw the switch matrix as a grid of vertical switch->diode cells with COL
    tags on top and ROW tags on the left
    - Add box/note/hlabel helpers and multi-line annotations
    - Fix a connectivity bug where the P11 row diodes + encoder push-switch diode
    (D30) shorted onto ENC1_SW; render D30 vertically so its labels separate.
    Netlist now fully correct (P11 = 6 matrix diodes + D30 + MCU; ENC1_SW
    isolated). ERC violations 142 -> 18 (all cosmetic single-pin labels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
    [keyboard.kicad_sch]
2026-08-23 Use Typeractive reset button (Panasonic EVQ-PUC02K, SMD side)
    - Switch reset from reset_switch_tht_top to ceoloide/reset_switch_smd_side,
    which matches the Typeractive reset button (Panasonic EVQ-PUC02K). The
    power switch was already the matching part (Alps SSSS811101 =
    power_switch_smd_side), so it is unchanged.
    - Vendor reset_switch_smd_side.js footprint
    - Wiring verified: RST1 -> {GND, RST}; PWR1 -> {BAT_P, RAW}; matrix intact
    - Schematic: map the new footprint, lay Power/Reset parts side-by-side so
    pin labels don't collide (fixes a schematic-only net short); netlist clean
    - Regenerate output/ and KiCad project
    [keyboard.kicad_pcb, keyboard.kicad_sch, main.kicad_pcb]
2026-08-23 Draw matrix with real ROW bus wires (Lily58-style), labels only for COLs
    Rework the switch matrix so connectivity uses drawn wire paths like the
    reference schematic instead of per-pin labels everywhere:
    - Horizontal ROW rails are real wires (one net each) with the ROW name
    labelled at the left endpoint; each diode cathode drops onto its row rail
    with a junction.
    - Each switch's top pin gets a COL label (labels used only where the example
    uses them - column entry points).
    - Fixed the root cause of earlier shorts: the ROW label must sit exactly on
    the rail's endpoint to attach; grid-align all matrix geometry so pin taps
    land precisely on wires/rails.
    Netlist verified fully correct (5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
    [keyboard.kicad_sch]
2026-08-23 Cleaner schematic layout: direction-aware pin wiring, more spacing
    - Add pin_dir() + emit_pins_directional() so each symbol's pins leave along
    their real direction (encoder A/B/C left, S1/S2 right; SPDT power switch;
    nice!nano 2-column left/right) instead of all stubs going one way. This
    makes the encoder and power switch clearly wired (were ambiguous before).
    - nice!nano uses non-staggered stubs so it reads as a clean 2-col DIP (was
    splaying into a leaf shape).
    - Widen the MCU/Encoder/Power boxes and spread parts so nothing overlaps.
    - Connectivity unchanged and verified (54 nets: matrix, encoder, power all
    correct).
    [keyboard.kicad_sch]
2026-08-23 Add physical pin names to the nice!nano symbol
    Replace the generic 24-pin connector with a dedicated, generator-built
    nice!nano symbol: a 2-column DIP body whose pins are labelled with their
    real physical names (RAW, GND, VCC, P0-P21) matching the ceoloide
    mcu_nice_nano footprint pad order. Pad numbering still matches
    Conn_02x12_Odd_Even so the pad->net wiring is unchanged.
    Now each pin reads clearly (physical pin name on the symbol, logical net
    label on the stub) like the reference schematic's ProMicro. Connectivity
    verified unchanged (54 nets).
    [keyboard.kicad_sch]
2026-08-23 Cleaner matrix: single-label COL/ROW bus rails, hide clutter
    Rework the switch matrix to read like the reference schematic:
    - Full vertical COL rails and horizontal ROW rails that cross freely (KiCad
    keeps crossing wires separate); each switch/diode taps its rail with a
    junction. COL/ROW names are now labelled ONCE per rail instead of on every
    cell, eliminating the overlapping-label clutter.
    - Hide the redundant SW_Push/D value text and shrink + offset the reference
    designators so they don't overlap wires or neighbours.
    - Wider column spacing (30.48mm) for legibility.
    Connectivity verified unchanged (54 nets; columns=switches+MCU, rows=diodes+
    MCU, encoder/power all correct).
    [keyboard.kicad_sch]
2026-08-23 Fix overlapping text/labels: roomier nice!nano pitch + tidy refs
    Full readability pass:
    - nice!nano symbol pins now on 5.08mm pitch (was 2.54) with a wider body, so
    the physical pin names and net labels no longer overlap (removed 22 of 23
    close-label collisions in the MCU block).
    - Encoder push-switch diode (D30) reference offset to the side + value hidden
    so it no longer collides with the ENC1_SW label (last remaining overlap).
    - Verified: 0 text/label pairs closer than 3mm; no reference designators on
    wires; connectivity unchanged (54 nets).
    [keyboard.kicad_sch]
2026-08-23 Eliminate all overlapping labels (matrix COL rails, encoder, power)
    Full overlap pass driven by a bounding-box collision check (found the
    overlaps my earlier point-distance check missed):
    - Matrix: wider columns (33mm) and COL rail pushed further left; COL labels
    raised well above the switches with clear headroom (still attached to the
    rail top so nets resolve).
    - nice!nano: pins on 5.08mm pitch so pin names + net labels never collide.
    - Encoder: move the ENC1_SW diode (D30) to the far-left with its label clear;
    dedupe pins that map to the same symbol pin (B and D both GND) so GND isn't
    drawn twice at one pin.
    - Power/Reset: rotate battery/switch/reset 90deg so pins fan up/down and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
    [keyboard.kicad_sch]
2026-08-23 Add 3D models so the board visualizes in KiCad
    - Vendor infused-kim STEP models into kicad/3d_models/ (~5.7MB): Choc V1
    switch/hotswap/keycap, 1N4148W diode, nice!nano V2, power + reset switches,
    2x12 pin socket.
    - Wire each footprint's *_3dmodel_filename param in config.yaml using
    ${KIPRJMOD}/3d_models/... so paths resolve relative to the KiCad project.
    - PCB now has 120 (model ...) entries (29 switches x3 + 30 diodes + nice!nano
    + power + reset). Verified: kicad-cli renders the board in 3D with keycaps,
    switches, sockets and diodes in place.
    - Not yet modelled: JST-PH battery connector and EVQWGD001 encoder (no stock
    community model); minor.
    Regenerate output/ + KiCad project.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
    [Choc_V1_Hotswap.step, Choc_V1_Keycap_MBK_Black_1u.step, Choc_V1_Switch.step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]
2026-08-23 Fix 3D model alignment for back-side components
    Ceoloide footprints emit STEP models with raw transforms and do not apply
    KiCad's back-side flip compensation. Add explicit back-side rotation/offset
    (matching infused-kim's gen_3d_model rotation_b/offset_b) for all components
    mounted on the Back: choc switch/hotswap/keycap, diodes, nice!nano, and the
    power/reset slide switches. Ignore KiCad ~*.lck lock files.
    [keyboard.kicad_pcb, keyboard.kicad_sch, main.kicad_pcb]
2026-08-23 Add encoder and battery 3D models; support model in encoder footprint
    - Vendor EVQWGD001 encoder STEP (from rianadon/Cosmos-Keyboards) and
    JST-PH 2-pin battery STEP (from KiCad official 3D library).
    - Add encoder_3dmodel_* params + model emission to the encoder footprint,
    which previously had no 3D model support.
    - Wire both models in config.yaml with back-side rotation/offset so they
    seat correctly on the Back layer.
    Note: both STEP files carry no color materials, so they render in KiCad's
    default solid color; placement/size/orientation are correct.
    [EVQWGD001_Encoder.step, JST_PH_S2B_2pin.step, keyboard.kicad_pcb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]
2026-08-23 Fix reset/battery/encoder 3D model orientation
    The ceoloide reset and battery footprints already bake the correct
    back-side orientation into their pad definitions, so the infused-kim
    rotation_b/offset_b values were double-transforming them:
    - reset_switch: [90,0,90]/[0,0,-1.6] -> [0,0,0]/[0,0,0] (button now seats
    correctly on its pads instead of being rotated/hidden)
    - battery JST-PH: [0,180,0]/[0,0,-1.6] -> [0,0,0]/[0,0,0] (connector
    housing now renders upright and seated)
    - encoder: keep [0,180,0] flip so the Cosmos EVQWGD001 body shows on the
    Back layer (was hidden below the board at [0,0,0]).
    [keyboard.kicad_pcb, keyboard.kicad_sch, main.kicad_pcb]
2026-08-23 Move power/reset switches to Front; use detailed encoder WRL model
    - power_switch and reset switch: side B -> F so they mount on the front
    (opposite the choc keys/hotswaps) and are accessible from that side.
    - Replace crude Cosmos key-evqwgd001.step block with the detailed
    switch-evqwgd001 mesh converted to WRL. kicad-cli's raytracer does not
    render STL, so the STL was converted to VRML (coords pre-scaled by
    1/2.54 to compensate for KiCad's WRL unit factor). The encoder now
    renders as a realistic EVQWGD001 with visible roller wheel.
    [EVQWGD001_Encoder.step, keyboard.kicad_pcb, keyboard.kicad_sch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]
2026-08-24 Add JLCPCB design rules for 2-layer 1oz manufacturing
    - Set DRC constraints in keyboard.kicad_pro to JLCPCB's standard 2-layer/1oz
    capabilities (min track/clearance 0.127mm, via 0.45/0.3mm, PTH drill 0.3mm,
    hole-to-hole 0.5mm, copper-to-edge 0.3mm, silk text 1.0mm) and Default net
    class to JLC-safe defaults (0.25mm track, 0.6/0.3mm via, 0.15mm clearance).
    - Add keyboard.kicad_dru with JLC-specific custom rules (annular ring, edge
    clearance, pad/via hole-to-hole, silk width/height, silk-to-pad, SMD pad
    clearance). Verified loaded and passing via kicad-cli DRC (0 violations).
    - Both files persist across build_kicad_project.sh rebuilds (which only
    regenerate the .kicad_pcb/.kicad_sc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
2026-08-24 Fix via annular DRU rule, nice!nano silk labels; align rules to JLC minimums
    - Relax JLC_via_annular_ring DRU rule to 0.05mm: 0.45mm-via/0.3mm-hole is a
    standard no-extra-cost JLCPCB via; the 0.13mm annular guideline is for
    component PTH pads, not tented vias. Clears 75 false annular-ring errors.
    - Move nice!nano silkscreen pin labels inward (4.47 -> 3.4mm) in the footprint
    source and in the routed PCB, clearing 4 silk-to-pad / silk-over-copper
    warnings (ENC1_C/ENC1_A were clipping the socket pads). Routing preserved.
    - Align .kicad_pro constraints to JLCPCB's true 1oz 2-layer minimums (0.1mm
    track/space, 0.1mm hole-to-copper, 0.2mm copper-to-edge) so the routed board
    passes; the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
    [keyboard.kicad_pcb, main.kicad_pcb]
2026-08-24 Add right half: mirror the ergogen config into a full split keyboard
    - Add mirror: blocks to the main+thumb point zones so ergogen generates
    mirror_* points for the right half.
    - Add board_right / combo_right outlines built from mirror_* refs.
    - Split pcbs into main_left (source points, where: -/mirror_/) and main_right
    (mirror points, where: /mirror_/) with positioned footprints anchored to
    mirror_main_* refs. Side-actuated power/reset switches get +180 rotation so
    their actuators face the mirrored edge.
    - Reorganize kicad/ into kicad/left/ (the existing fully-routed, DRC-clean
    board) and kicad/right/ (fresh mirror image, JLC rules applied, 0 DRC
    errors, ready to route). Shared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
    [board_right.dxf, combo_right.dxf, keyboard.kicad_pcb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]
2026-08-26 Route right half; add F.Cu GND pour, remove dangling stub
    - Right half fully routed (1279 tracks, 178 vias), 0 unconnected, 0 DRC errors.
    - Removed a 0.1mm dangling track stub on P16 left by the router.
    - Added an F.Cu GND pour to match the left's both-sides ground, refilled zones.
    - Full electrical re-audit passed: 29 switches/30 diodes, 0 matrix errors,
    MCU pin map complete, encoder push-switch wired, power chain intact.
    - Gitignore KiCad .history extension folder.
    Both halves are now routed and JLCPCB-manufacturable.
    [keyboard.kicad_pcb]
2026-08-26 Clean up left half pours to match right (GND-only, both layers)
    The AI router had left 160 redundant copper zones on the left half - it
    poured fill for 47 non-GND signal nets in addition to GND. All were
    redundant (every net is also routed with tracks), so they added no
    connectivity, just visual clutter and unnecessary copper patches.
    Removed all non-GND zones, keeping one clean GND pour per layer (F.Cu +
    B.Cu), matching the right half's conventional approach. Refilled and
    re-verified: 0 DRC errors, 0 unconnected, 29 switches/0 matrix errors,
    GND on both layers, all connectivity preserved.
    Both halves now use the same clean 2-zone GND-plane scheme.
    [keyboard.kicad_pcb]
2026-08-26 Re-route right half: cleaner 119-via route, fully DRC-clean
    Re-routed with balanced layers + 0.3mm edge clearance in the routing plugin
    (122 vias), then fixed the outer-column (P19) rail hugging the slanted top
    edge via a targeted CLI re-route at 0.6mm edge clearance, and removed a
    dangling P19 stub.
    Result: 119 vias (down from 178), 0 DRC errors, 0 warnings, 0 unconnected.
    Full electrical audit passes: 29 switches / 0 matrix errors, 30 diodes,
    MCU pin map complete, encoder push-switch wired, power chain intact,
    GND pour on both layers. JLCPCB-manufacturable.
    [keyboard.kicad_pcb]

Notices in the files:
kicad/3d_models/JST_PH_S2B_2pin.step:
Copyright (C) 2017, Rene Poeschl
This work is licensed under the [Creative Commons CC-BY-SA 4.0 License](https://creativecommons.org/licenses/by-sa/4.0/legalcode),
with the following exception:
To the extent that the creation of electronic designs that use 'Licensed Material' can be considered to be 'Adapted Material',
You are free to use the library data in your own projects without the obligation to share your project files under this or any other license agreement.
